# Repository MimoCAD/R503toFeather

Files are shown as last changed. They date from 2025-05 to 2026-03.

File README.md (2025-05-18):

# Pinout

## Adafruit Feather RP2350 HSTX
Adafruit Feather RP2350 HSTX Pinout

## Grow R503 Pro
GROW R503 Pro MX1.0-6P Pinout

## Connections
| # | R503 Pro Wire Color | Name | PIN # | Pin Name | Notes |
| - | :---: | :---:  | :---: | :---: | :---: |
| 1 | $${\color{red}RED \space Wire}$$ | Power  | 3V3 | $${\color{red}3V3}$$ | 3.3 Volts (Top Left Of Feather). |
| 2 | $${\color{black}BLACK \space Wire}$$ | GND | GRD | $${\color{black}GND}$$ | Ground (Right Under 3.3 Pins). |
| 3 | $${\color{yellow}YELLOW \space Wire}$$ | TXD | 01 | $${\color{green}RX}$$  | TX on R503 <> RX on the Feather. |
| 4 | $${\color{green}GREEN \space Wire}$$ | RXD | 00 | $${\color{yellow}TX}$$ | RX on R503 <> TX on the Feather. |
| 5 | $${\color{blue}BLUE \space Wire}$$ | Wakeup | 02 | $${\color{BLUE}SDA}$$  | Finger Detection (Pulled High).  |
| 6 | $${\color{white}WHITE \space Wire}$$ | Touch  | 3V3 | $${\color{red}3V3}$$ | 3.3 Volts (Top Left Of Feather). |

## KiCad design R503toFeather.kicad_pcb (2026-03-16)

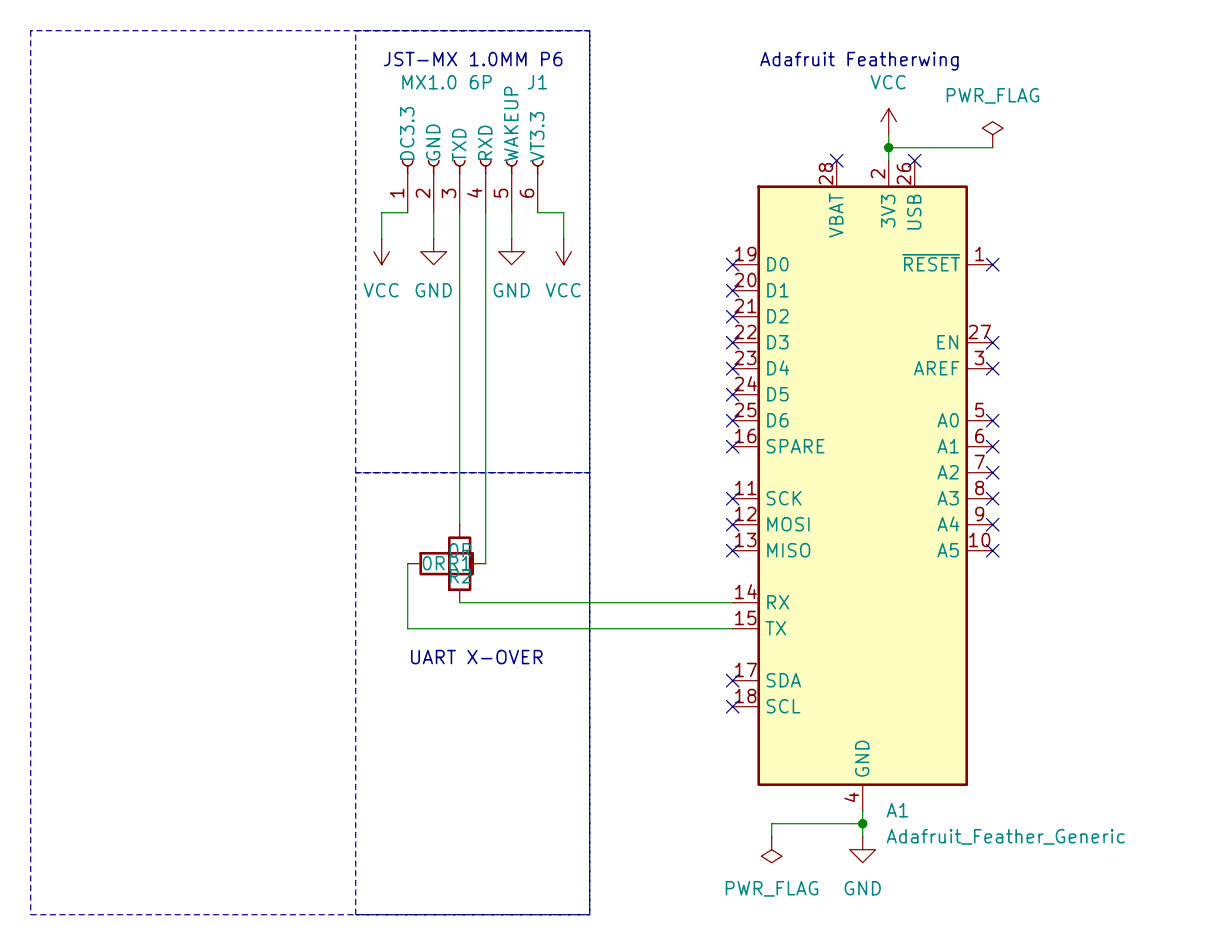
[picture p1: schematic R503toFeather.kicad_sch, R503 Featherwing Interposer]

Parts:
A1: Adafruit_Feather_Generic; Adafruit_Feather
J1: MX1.0 6P; JST_SHL_SM06B-SHLS-TF_1x06-1MP_P1.00mm_Horizontal
R1, R2: 0R; R_1206_3216Metric

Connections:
GND: A1.4 (GND), J1.2 (GND), J1.5 (WAKEUP)
unnamed: A1.14 (RX), R2.2
unnamed: A1.15 (TX), R1.2
unnamed: J1.4 (RXD), R1.1
unnamed: J1.3 (TXD), R2.1
VCC: A1.2 (3V3), J1.1 (DC3.3), J1.6 (VT3.3)

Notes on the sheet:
UART X-OVER
JST-MX 1.0MM P6
Adafruit Featherwing

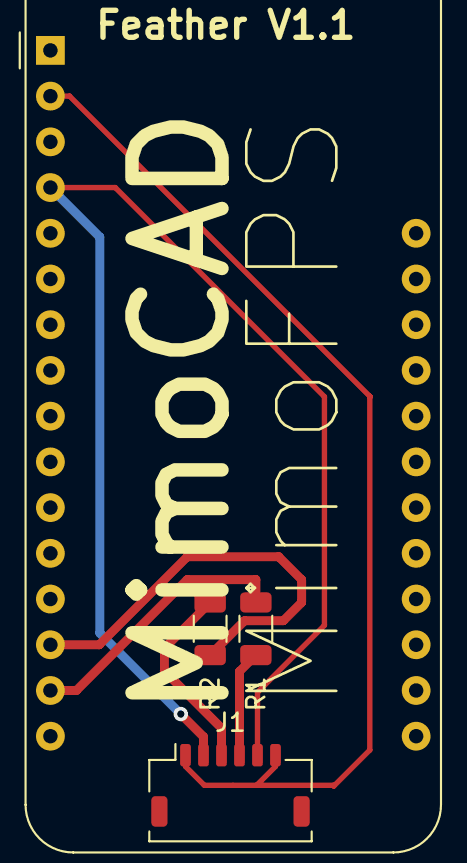
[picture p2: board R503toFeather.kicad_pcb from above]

Board: 2 copper layers, 4 parts (0 on the bottom side), 6 nets.

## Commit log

2024-08-15 Hopefully Functional.
    [R503toFeather-B_Cu.gbr, R503toFeather-B_Mask.gbr, R503toFeather-B_Paste.gbr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]
2025-05-18 RP2350 HSTX Production Version
    [R503toFeather-B_Cu.gbr, R503toFeather-B_Mask.gbr, R503toFeather-B_Paste.gbr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]
2026-03-16 Fixed J1's 2 Pin. Corrected to GND.
    [R503toFeather.kicad_pcb, R503toFeather.kicad_sch]

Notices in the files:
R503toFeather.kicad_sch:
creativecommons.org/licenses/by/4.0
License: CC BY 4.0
